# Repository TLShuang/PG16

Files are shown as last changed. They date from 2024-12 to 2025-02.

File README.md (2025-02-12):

# Suitcase Synth Modulino

[LEARN ABOUT OUR PROCESS THROUGH THIS PROJECT IN THE POTENTIALLY GENIUS SERIES](https://youtu.be/-QRer8uG97s?si=7fIsf5wegiuD1a32)

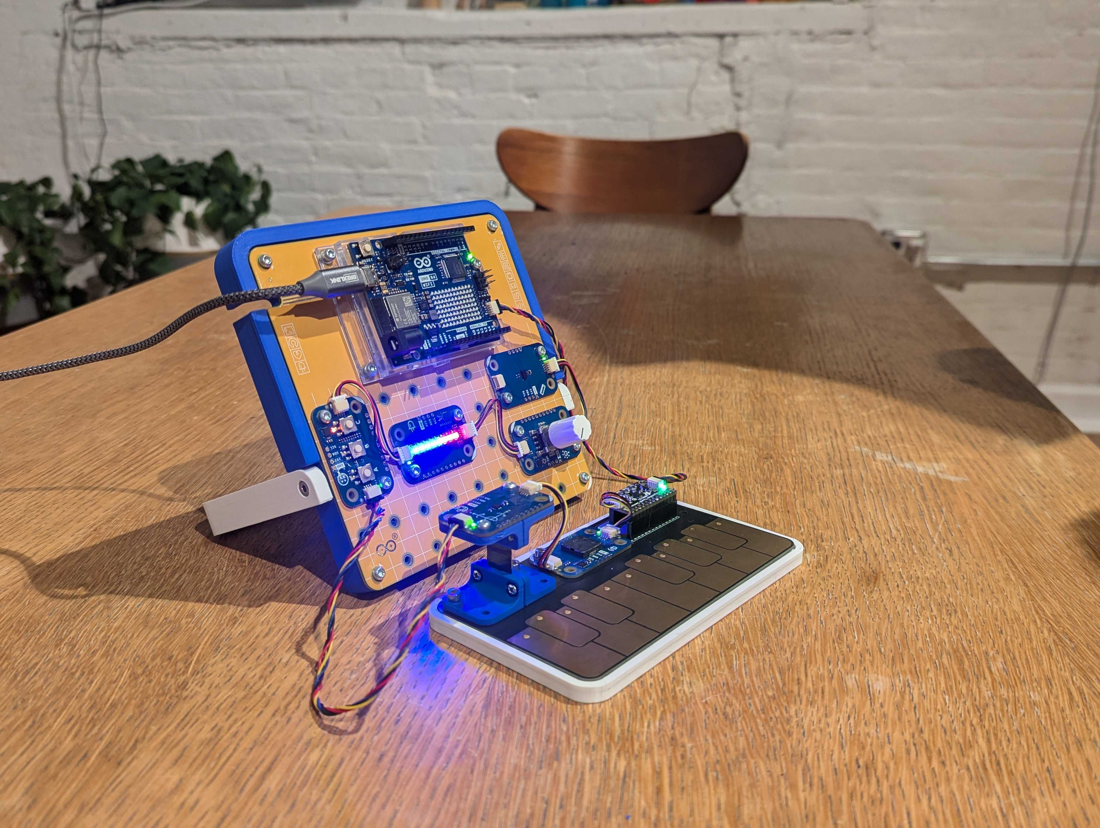
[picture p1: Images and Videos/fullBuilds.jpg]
full build


## Overview
Building on Plug and Make Kit, the Suitcase Synth Modulino is a portable, modular sound synthesizer that combines capacitive touch, sensor-driven sound manipulation, and visual feedback. Built for creativity and interaction, it allows users to explore monophonic sound creation, pitch bending, vibrato effects, and more, through intuitive controls and modular components.

---

## Features
- **Capacitive Touch Keys**: Play 12 notes with adjustable octaves.
- **Modular Interaction**:
  - **Knob Modulino**: Adjust vibrato speed and enable/disable vibrato.
  - **ToF Distance Sensor Modulino**: Dynamically control vibrato depth.
  - **Accelerometer Modulino**: Tilt control for pitch bending.
- **Visual Feedback**:
  - LED Matrix displays note names and sine wave visualizations.
  - LED strip provides dynamic color changes based on input.
- **Sound Engine**: Generates sounds via a monophonic buzzer with modulation effects like vibrato and pitch bending.
- **Octave Control**: Select octave range using buttons with LED indicators.

---

## Setup
### Physical Setup and Components
- Plug and Make Kit with modulinos
- Modulino Buzzer, Buttons, Knob, Distance, Movement, and Pixels
- Power supply (USB or battery)
- Adafruit MPR121 Capacitive Touch Sensor
- TL synth PCB or any capacitive items
- 3D printer

### Software Setup
We used the following software to design this project. To recreate, you may use the following or use the provided file directly. You may also choose softwares that you feel comfortable using.
- Fusion 360 (Schematic and PCB)
- Solidworks (Enclosure Design)
- Bambu Studio (3D Printing Slicer)
- Arduino IDE (Programming)

### Assembly
1. Connect the MPR121 sensor on PCB for capacitive touch input. You can directly solder the MPR121 with male headers or use female headers.
2. Attach all Modulino components to the microcontroller and on the mainboard or plateboard. You can use threaded M3 heats insert or thread forming screws to attach them on to your 3D print.
3. Connect all the used Modulino with the Qwiic connectors provided in the kit.
4. Upload the provided code to your Arduino.

---

## How It Works
1. **Playing Notes**: Touch the capacitive keys to produce sounds.
2. **Octave Selection**: Use the buttons to switch between octaves. LEDs indicate the current octave.
3. **Sound Manipulation**:
   - Rotate the knob to adjust vibrato rate.
   - Move your hand over the ToF sensor to change vibrato depth.
   - Tilt the accelerometer to bend the pitch.
4. **Visual Feedback**: Note names, sine wave patterns, and color changes synchronize with your interaction.

---

## Code Highlights
- **Capacitive Touch**: Detects note presses and controls sound generation.
- **Vibrato Effect**: Adds a modulated frequency offset based on knob and ToF sensor input.
- **Pitch Bending**: Dynamically modifies pitch using accelerometer data.
- **Visuals**: LED Matrix displays note and sine wave data; LED strip reacts to pitch and vibrato changes.

---

## Usage
1. Turn on the Suitcase Synth Modulino.
2. Touch the keys to play notes.
3. Use the knob, distance sensor, and accelerometer for live sound effects.
4. Observe the visual feedback for an immersive experience.

---

## Applications
- Interactive sound installations.
- Music education and experimentation.
- Open-source hardware exploration.

---

## Future Expansion
The modular design allows users to add new sensors or outputs, enabling endless creative possibilities.

## License
This project is open-source and part of the Arduino Plug and Make Kit ecosystem.

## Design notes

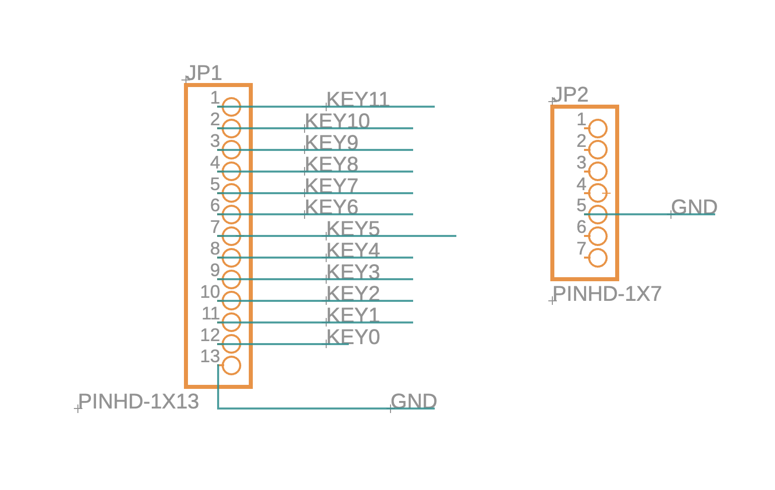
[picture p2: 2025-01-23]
PCB/Schematic.png

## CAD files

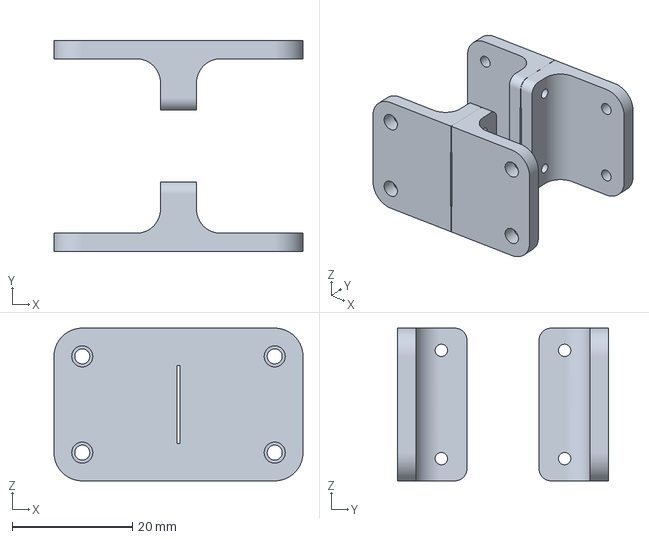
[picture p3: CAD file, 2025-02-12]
Enclosures/PGSynth_PitchBend-Assem.3MF
41.4 x 35.0 x 25.4 mm

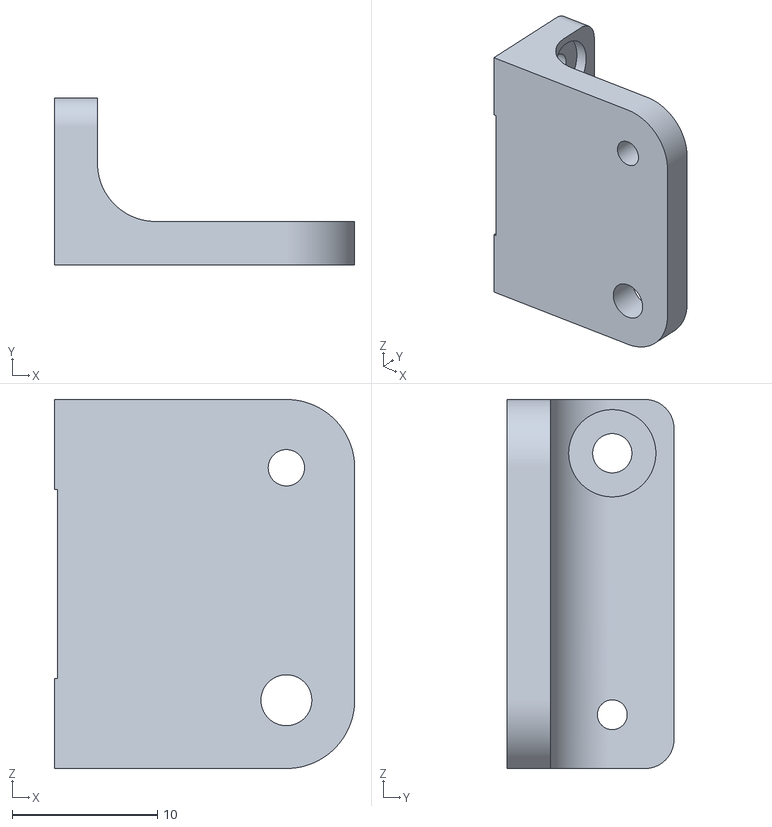
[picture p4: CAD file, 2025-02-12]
Enclosures/PGSynth_PitchBend-section.STL
20.7 x 11.5 x 25.4

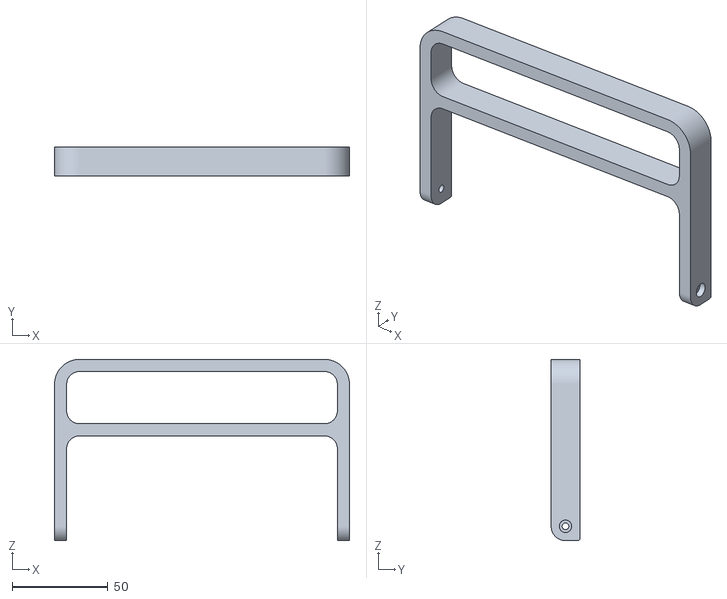
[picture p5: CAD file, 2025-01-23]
Enclosures/PGSynth_Handle.STL
154.2 x 15.0 x 94.8

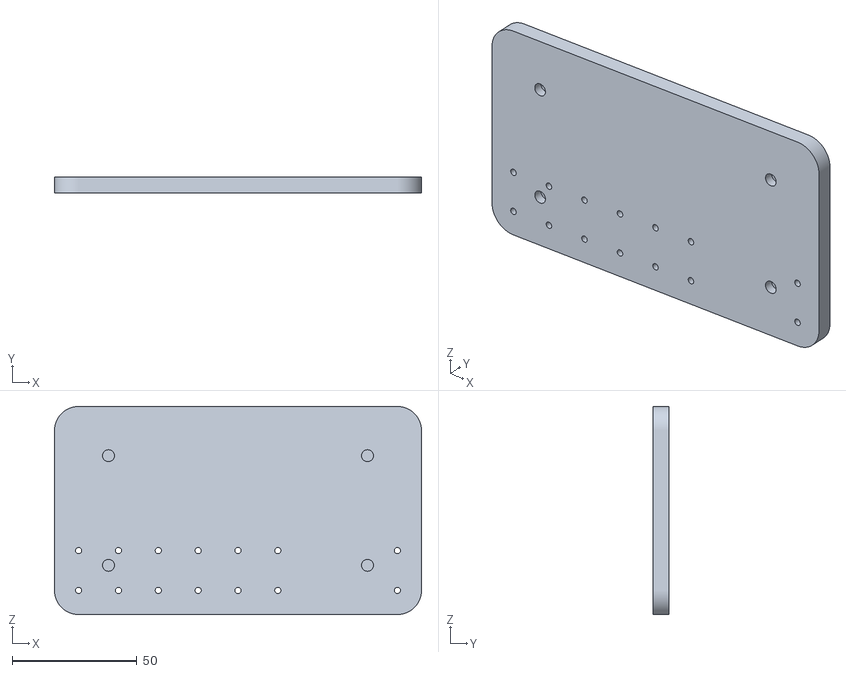
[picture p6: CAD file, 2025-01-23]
Enclosures/PGSynth_KeyboardFrame.STL
147.4 x 6.35 x 83.6

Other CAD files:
PCB/PCBPlates v76.f3z

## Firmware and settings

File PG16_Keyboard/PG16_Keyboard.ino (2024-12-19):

#include <Wire.h>
#include "Adafruit_MPR121.h"
#include <Modulino.h>
#include "ArduinoGraphics.h"
#include "Arduino_LED_Matrix.h"


#ifndef _BV
#define _BV(bit) (1 << (bit))
#endif

// Create MPR121 and ModulinoBuzzer instances
Adafruit_MPR121 cap = Adafruit_MPR121();
ModulinoBuzzer buzzer;
ModulinoButtons buttons;
ModulinoKnob knob;
ModulinoDistance distanceSensor;
ModulinoMovement movement;
ModulinoPixels leds;
ArduinoLEDMatrix matrix;

//Extra LED strip colors
ModulinoColor YELLOW(255, 255, 0);
ModulinoColor OFF(0, 0, 0);

// Stack to keep track of pressed keys
int pressedStack[12];  // Stack to hold active keys
int stackIndex = -1;   // Track the current top of the stack
float scaleFactor = 1.0;

// Array to store frequencies for each pad
int padFrequencies[12] = { 523, 554, 587, 622, 659, 698, 740, 784, 831, 880, 932, 988 };
int adjustedFrequencies[12] = { 523, 554, 587, 622, 659, 698, 740, 784, 831, 880, 932, 988 };
char noteNames[][12] = { "C", "C#", "D", "D#", "E", "F", "F#", "G", "G#", "A", "A#", "B" };
int currentOctave = 0;  // Default to octave 0

// Keeps track of the last pads touched and the currently playing frequency
uint16_t lasttouched = 0;
uint16_t currtouched = 0;
bool isPlaying = false;    // Track if the tone is currently playing
int currentFrequency = 0;  // Track the current playing frequency

//Knob setup
bool knobPressed = false;
int lastKnobValue = 0;
bool knobPriority = false;
bool lockout = false;
unsigned long knobLastMovedTime = 0;

//bar graph holder frame
uint8_t frame[8][12] = { 0 };
unsigned long lastDisplayTime;
int graphDelay_ms = 1000;

//Vibrato control
bool vibratoEnabled = false;        // Whether the vibrato effect is active
float vibratoDepth = 0.0;           // Maximum frequency deviation (e.g., ±10 Hz)
float vibratoDepthBackup = 6.0;     //store value when disabled
float vibratoRate = 0.0;            // How fast the frequency oscillates (e.g., 5 Hz)
float vibratoRateBackup = 3.0;      //store value when disabled
unsigned long lastVibratoTime = 0;  // Used for time tracking
float vibratoDepthMax = 20.0;
float vibratoRateMax = 10.0;

//Accelerometer variables
float tiltValue = 0;
float pitchMultiplier = 1.0; //for pitch bend


void playSound(int frequency) {

  //Vibrato calculation
  int vibratoOffset = 0;

  if (vibratoEnabled) {
    // Calculate elapsed time
    unsigned long currentTime = millis();
    float elapsedTime = (currentTime - lastVibratoTime) / 1000.0;  // Convert ms to seconds

    // Calculate vibrato using a sine wave (or use `sin()`)
    vibratoOffset = vibratoDepth * sin(2 * PI * vibratoRate * elapsedTime);

    // Update time tracking (reset every cycle)
    if (elapsedTime > (1.0 / vibratoRate)) {
      lastVibratoTime = currentTime;
    }
  }

  //play tone
  int modulatedFrequency = frequency + vibratoOffset;
  buzzer.tone(modulatedFrequency, 65);  // Short duration to simulate continuous tone
  currentFrequency = frequency;
  isPlaying = true;
}


void stopSound() {
  if (isPlaying) {
    buzzer.noTone();
    isPlaying = false;
    currentFrequency = 0;
  }
}

void barGraph(int min, int max, int value, int height) {

  //Not used (alternative to sine wave visual)
  height = constrain(height, 1, 8);  // Height cannot exceed the matrix height (8 rows)

  // Calculate starting and ending rows for the bar
  int startRow = (8 - height) / 2;     // Center the bar vertically
  int endRow = startRow + height - 1;  // Determine the last row to fill

  // Clear the frame array
  memset(frame, 0, sizeof(frame));

  // Calculate how many columns to fill (0-12)
  int filledColumns = map(value, min, max, 0, 12);
  filledColumns = constrain(filledColumns, 0, 12);  // Ensure within matrix bounds

  // Draw the bar in the frame
  for (int x = 0; x < filledColumns; x++) {
    for (int y = startRow; y <= endRow; y++) {  // set height of graph line
      frame[y][x] = 1;                          // Turn on the pixel at (x, y)
    }
  }
  // Render the frame to the matrix
  matrix.renderBitmap(frame, 8, 12);

  lastDisplayTime = millis();
}

//map function that works with floats
float mapFloat(float x, float in_min, float in_max, float out_min, float out_max) {
  return (x - in_min) * (out_max - out_min) / (in_max - in_min) + out_min;
}

void sineWaveGraph() {
  // Clear the frame
  memset(frame, 0, sizeof(frame));  // Clear the frame array
  // Map vibratoDepth to sine wave amplitude
  int amplitude = map(vibratoDepth, 0, vibratoDepthMax, 0, 6);
  amplitude = constrain(amplitude, 0, 6);  // Ensure within matrix bounds

  // Use mapFloat to calculate cycles as a float
  float cycles = mapFloat(vibratoRate, 0, vibratoRateMax, 0.0, 4.0);  // Number of cycles

  // Angle step for sine wave
  float step = (2.0 * PI * cycles) / 12.0;

  // Calculate the center of the matrix
  int centerX = 12 / 2;  // Center column (6 for a 12-column matrix)

  // Draw the sine wave symmetrically from the center outwards
  for (int offset = 0; offset <= centerX; offset++) {
    for (int sign = -1; sign <= 1; sign += 2) {  // Calculate left and right columns relative to the center
      int x = centerX + (sign * offset);         // Column index moving symmetrically outward

      if (x >= 0 && x < 12) {                             // Ensure x is within matrix bounds
        float normalizedX = (float)(x - centerX) / 12.0;  // Normalize distance from center
        float angle = 2.0 * PI * cycles * normalizedX;    // Angle for sine calculation
        int yCenter = 4;                                  // Center of the sine wave vertically
        int y = yCenter + round(amplitude * sin(angle));  // Calculate y position

        // Constrain y to stay within matrix bounds
        y = constrain(y, 0, 7);

        // Set the pixel at (x, y) to represent the main sine wave
        frame[y][x] = 1;

        // Ensure 2-row thickness by lighting up 1 row above the main row
        int thickenedY = max(0, y - 1);  // Make sure we don't go below row 0
        frame[thickenedY][x] = 1;        // Light up the row above the main y
      }
    }
  }
  // Render the frame to the matrix
  matrix.renderBitmap(frame, 8, 12);
  lastDisplayTime = millis();
}


// Push a key onto the stack
void pushKey(int key) {
  if (stackIndex < 11) {  // Ensure stack doesn't overflow
    pressedStack[++stackIndex] = key;
  }
}

// Remove a key from the stack
void popKey(int key) {
  for (int i = 0; i <= stackIndex; i++) {
    if (pressedStack[i] == key) {
      // Shift all elements down to remove the key
      for (int j = i; j < stackIndex; j++) {
        pressedStack[j] = pressedStack[j + 1];
      }
      stackIndex--;  // Decrement stack top
      break;
    }
  }
}

void handleButtons() {
  if (buttons.update()) {          // Check for button state changes
    for (int i = 0; i < 3; i++) {  // Iterate through the buttons
      if (buttons.isPressed(i)) {  // Check if button is pressed
        int newOctave = i - 1;     // Map button 0 to -1, button 1 to 0, button 2 to +1

        if (newOctave != currentOctave) {  // Only update if octave changes
          currentOctave = newOctave;

          // Update LEDs: only the current state's LED is on
          buttons.setLeds(currentOctave == -1, currentOctave == 0, currentOctave == 1);

          // Recalculate frequencies for the new octave
          for (int j = 0; j < 12; j++) {
            adjustedFrequencies[j] = padFrequencies[j] * pow(2, currentOctave);
          }

          // Debugging output for octave changes
          Serial.print("Current Octave: ");
          Serial.println(currentOctave);
        }
      }
    }
  }
}

void handleKnob() {
  float speedScale = .25;
  float value = knob.get();

  if (value > vibratoRateMax) {  // Set limits
    value = vibratoRateMax;
    knob.set(value);
  } else if (value < 0) {
    value = 0;
    knob.set(value);
  }

  if (value != lastKnobValue) {  //knob is being turned
    if (vibratoEnabled) {
      knobPriority = true;
      lockout = true;   //stop note name from displaying
      //barGraph (0, vibratoRateMax, value, 4);
      vibratoRate = value;
      lastKnobValue = value;
    }
    sineWaveGraph();
  }
  if (knob.isPressed() && !knobPressed) {  // Toggle vibrato when knob is pressed
    knobPressed = true;
    if (vibratoEnabled) {  //disable
      vibratoEnabled = false;
      //set values to zero temporarily for visualization
      vibratoDepthBackup = vibratoDepth;
      vibratoRateBackup = vibratoRate;
      vibratoDepth = 0;
      vibratoRate = 0;
      Serial.println("Vibrato disabled");
    } else {  //enable
      vibratoEnabled = true;
      //recall backed up values
      vibratoDepth = vibratoDepthBackup;
      vibratoRate = vibratoRateBackup;
      Serial.println("Vibrato enabled");
    }
    sineWaveGraph();
  } else if (!knob.isPressed() && knobPressed) {  //knob released, reset
    knobPressed = false;
  }
}

void handleTof() {
  if (distanceSensor.available()) {
    int measure = distanceSensor.get();
    if (measure < 200) {  //activate within a limited distance from the sensor
      //stop note names from displaying
      knobPriority = true;
      lockout = true;

      vibratoDepth = map((float)measure, 15, 180, 0, vibratoDepthMax);
      sineWaveGraph();
    } else {
      knobPriority = false;
    }
  } else {
    knobPriority = false;
  }
}

void setPixel(int pixel, ModulinoColor color) {
  leds.set(pixel, color, 15);
  leds.show();
}

void handleMovement() {
  movement.update();
  tiltValue = movement.getX(); //get x rotation value from IMU
  //dead zone in center
  if (tiltValue > -0.05 && tiltValue < 0.05) {
    tiltValue = 0;
  }
  pitchMultiplier = mapFloat(tiltValue, -0.3, 0.3, 1.122, 0.891);   //map range of tilt sensor to 1 whole step of pitch bend as a multiplier (2^-1/12 to 2^1/12)

  //Serial.println(tiltValue);
  int barGraphVal = int(mapFloat(tiltValue, -0.3, 0.3, 8.0, 0.0));  //map range to 8 bit led bar
  //update visual display on led bar
  for (int i = 0; i < 8; i++) {
    if (i <= barGraphVal) {
      setPixel(i, BLUE);
    } else {
      setPixel(i, RED);
    }
  }
}

void matrixText(char matrixText[]) {
  //take a char array and display it on the LED matrix
  Serial.println(knobPriority);
  if (!lockout) {   //don't display if knob or TOF are active
    matrix.clear();
    //LED Matrix Note Name
    matrix.beginDraw();
    matrix.stroke(0xFFFFFFFF);

    // add the text
    matrix.textFont(Font_5x7);
    matrix.beginText(4, 1, 0xFFFFFF);
    matrix.println(matrixText);
    matrix.endText();

    matrix.endDraw();
    lastDisplayTime = millis();
  }
}

void setup() {
  Serial.begin(9600);
  delay(2000);  // Give time for Serial to initialize
  Serial.println("Adafruit MPR121 Capacitive Touch sensor test");
  // Initialize the buzzer
  Modulino.begin();
  buzzer.begin();
  buttons.begin();
  knob.begin();
  movement.begin();
  leds.begin();
  matrix.begin();

  knob.set(vibratoRate);

  Serial.println("Initializing ToF Sensor...");
  if (!distanceSensor.begin()) {
    Serial.println("Failed to initialize ToF sensor! Check wiring and power.");
    while (1)
      ;  // Halt if sensor initialization fails
  }
  Serial.println("ToF Sensor initialized successfully.");

  buttons.setLeds(false, true, false);

  // Initialize Wire1 for the Qwiic connector and MPR121
  Wire1.begin();
  if (!cap.begin(0x5A, &Wire1)) {  // Use &Wire1 for the Qwiic port
    Serial.println("MPR121 not found, check wiring and I2C address!");
    while (1)
      ;
  }
  Serial.println("MPR121 found!");

  //clear pixel strip
  for (int i = 0; i < 8; i++) {
    setPixel(i, OFF);
  }
}

void loop() {
  // Get the currently touched pads
  currtouched = cap.touched();

  // Run all sensor handlers
  handleButtons();
  handleTof();
  handleKnob();
  handleMovement();

  // Check each pad to update the stack
  for (uint8_t i = 0; i < 12; i++) {
    if (currtouched & _BV(i)) {       // Check if pad i is currently pressed
      if (!(lasttouched & _BV(i))) {  // Only push if it was not already pressed
        pushKey(i);                   // Add newly pressed key to the stack
      }
    } else if (lasttouched & _BV(i)) {  // Pad was just released
      popKey(i);                        // Remove released key from the stack
    }
  }

  // Play the sound of the most recent key in the stack (last pressed)
  if (stackIndex >= 0) {
    int lastKey = pressedStack[stackIndex];
    if (adjustedFrequencies[lastKey] != currentFrequency) {  // Play new frequency if it changed
      playSound(adjustedFrequencies[lastKey] * scaleFactor * pitchMultiplier);
      matrixText(noteNames[lastKey]);  //display current note name
    } else {
      // Continue playing the current frequency if no changes
      playSound(currentFrequency * scaleFactor * pitchMultiplier);  //includes pitch bend multiplier
    }
  } else {
    stopSound();  // Stop sound if no keys are pressed
  }

  //keep latest displayed info on the screen for a period of 1 second
  if (millis() - lastDisplayTime > graphDelay_ms) {
    matrix.clear();
    if (!knobPriority) {
      lockout = false;  //reset note name lockout after time elapsed
    }
  }

  // Reset our state
  lasttouched = currtouched;
  delay(10);  // Small delay for smooth playback
}

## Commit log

2025-01-23 Create Enclosures
2025-01-23 Added STL
    [PGSynth_Handle.STL, PGSynth_KeyboardFrame.STL]
2025-01-23 PCB Added
    [PCBPlates v76.brd, PCBPlates v76.f3z, PCBPlates_v17.sch]
